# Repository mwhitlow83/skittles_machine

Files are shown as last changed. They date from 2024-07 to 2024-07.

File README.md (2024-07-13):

# skittles_machine
#### Machine that physically separates skittles candy by color

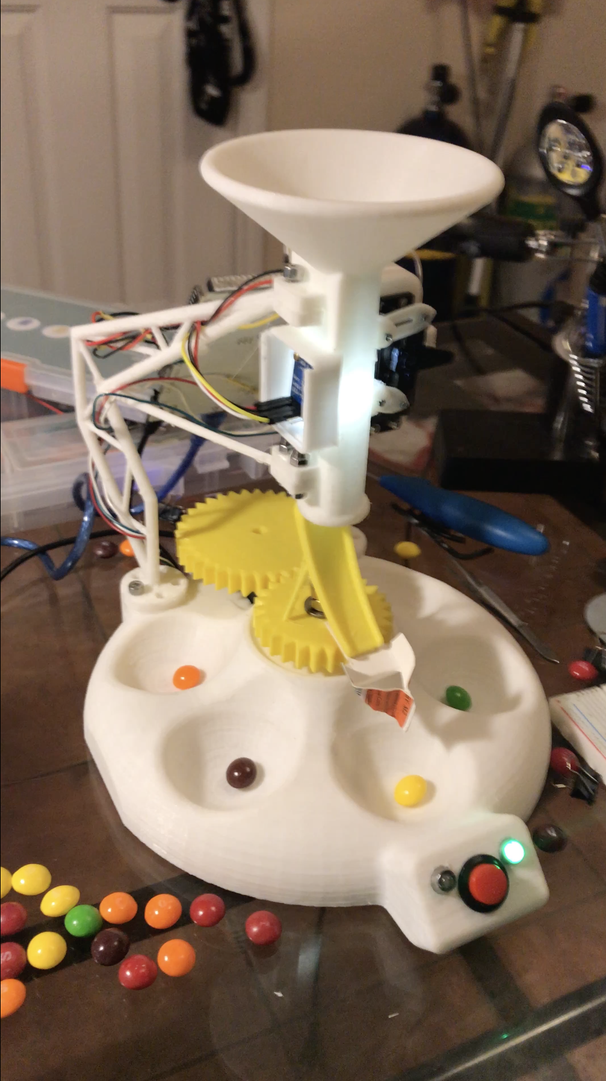
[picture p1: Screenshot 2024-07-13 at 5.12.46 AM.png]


#### Items Required 
Adafruit_TCS34725 color sensor, arduino, 2 servos, leds, resistors and button.

#### Description of operation
One servo is located under the larger gear. in order for the slide to reach 270 degrees of rotation with a servo thats limited to 180 degrees a gear system is needed.

The second servo is located in the processing housing and it operates in the means of allowing one skittle at a time to be analysed by the color sensor. See photo
 below.
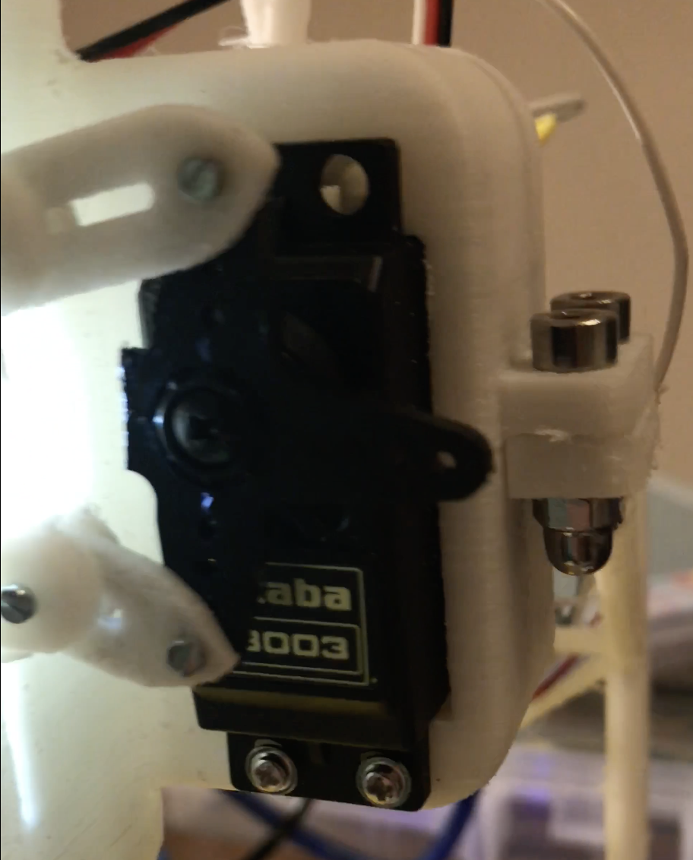
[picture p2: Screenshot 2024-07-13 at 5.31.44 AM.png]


#### Calibration may be needed
The raw ADC value range for each color are used in condiitonal statements to indentify the color. The range was calculated by recording the ADC values of 10 pieces of 1 color and then conditional boundaries are set in the code.

#### Additional Requirments
The initial drop of the skiddles down the sorting slide is greater that what is needed for the skittle not to bounce out of the container. A mechanical structure is needed to slow the velocity of the skittle at the botton of the slide.

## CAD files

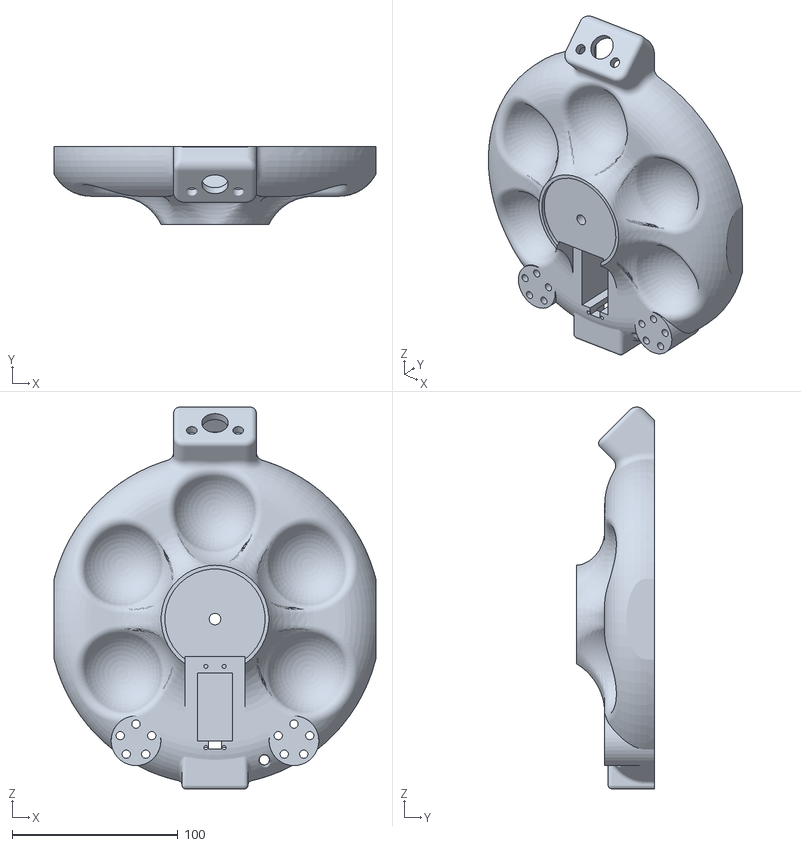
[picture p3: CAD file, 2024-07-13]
STL files/bin base shaved side.STL
194.0 x 47.0 x 230.4

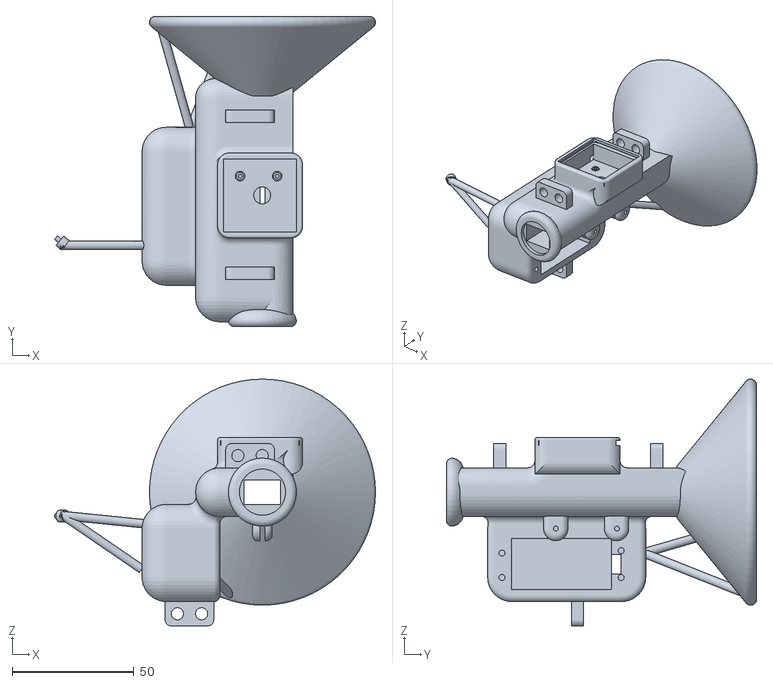
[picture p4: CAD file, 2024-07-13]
STL files/servo housing w color sensor.STL
132.0 x 127.6 x 101.5

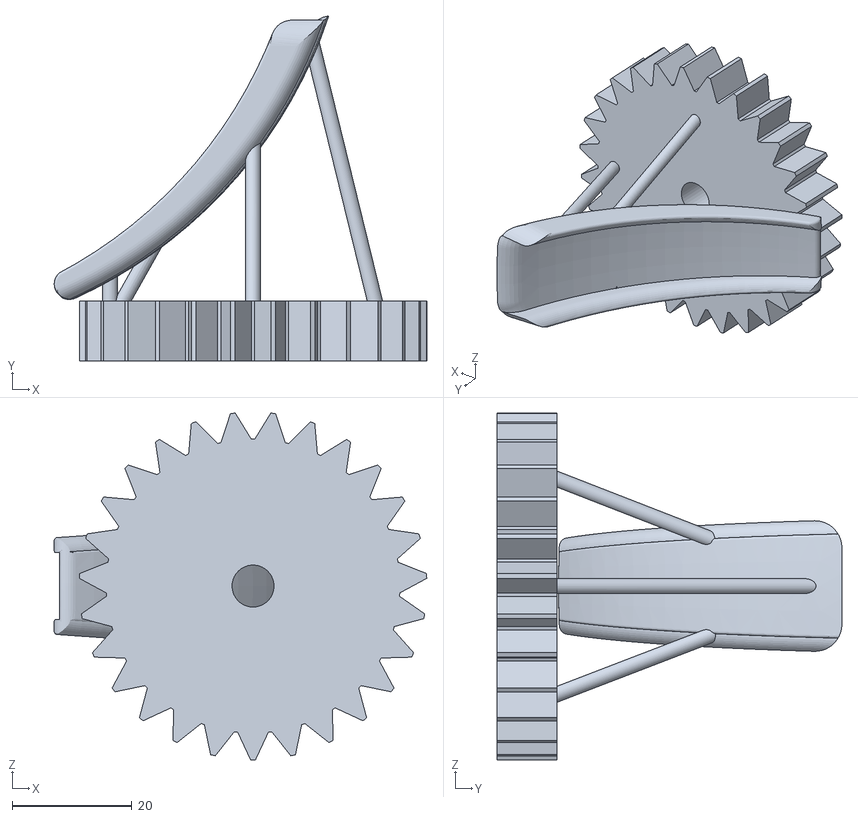
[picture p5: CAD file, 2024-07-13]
STL files/slide gear with slide.STL
62.1 x 57.5 x 57.9

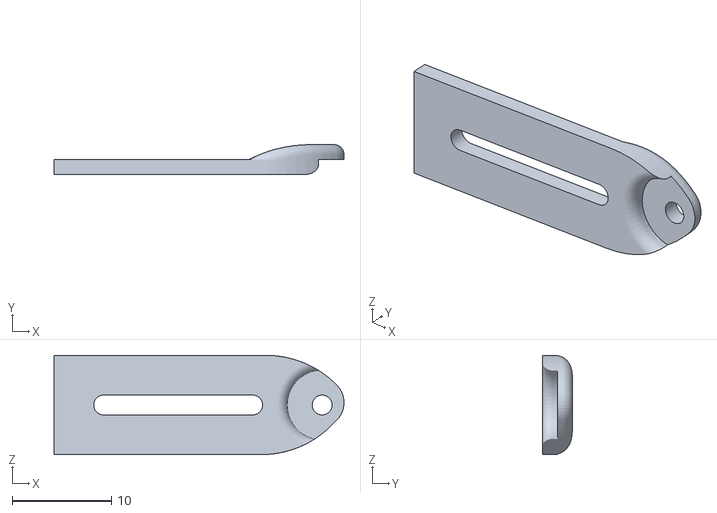
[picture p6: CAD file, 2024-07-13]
STL files/lower linkage.STL
29.2 x 3.00 x 10.0

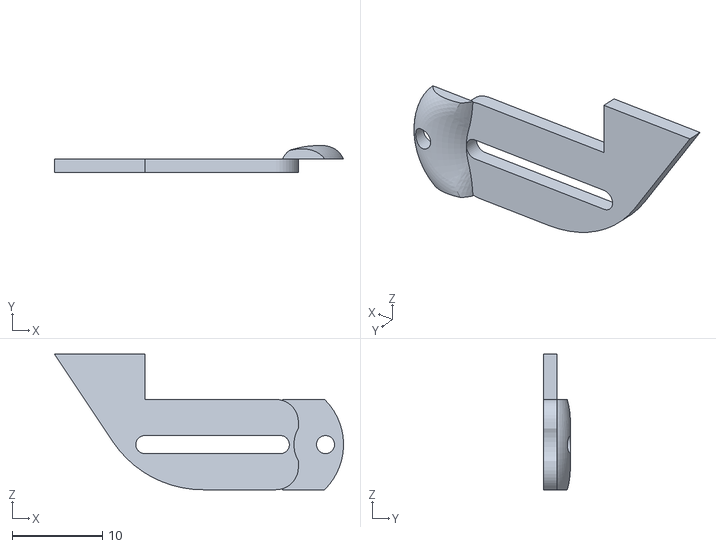
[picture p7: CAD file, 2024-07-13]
STL files/upper linkage.STL
32.0 x 3.00 x 15.0

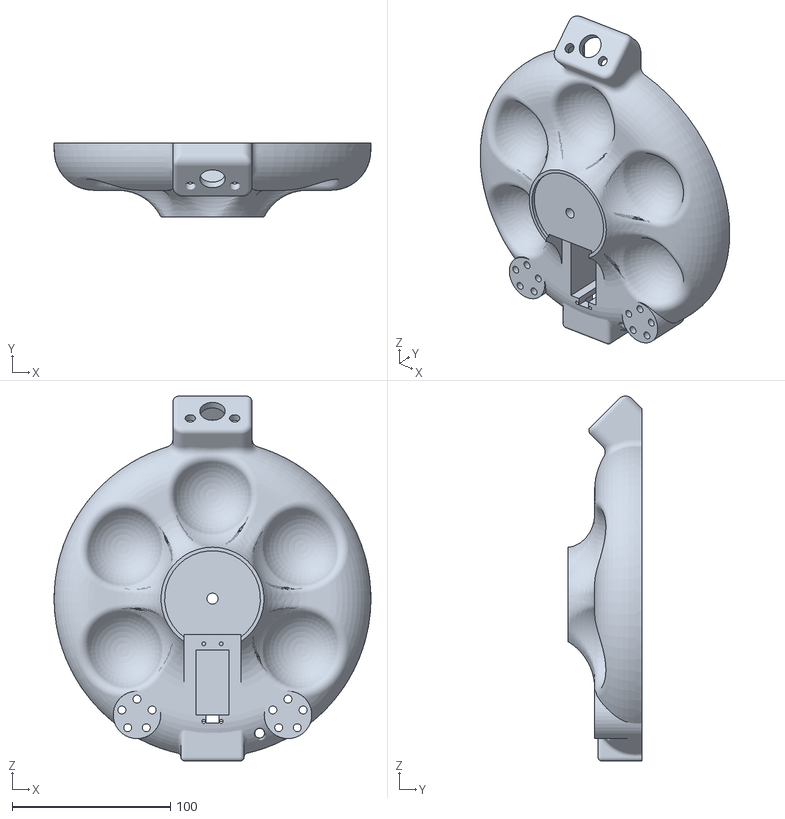
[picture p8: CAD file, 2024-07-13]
STL files/bin base.STL
199.9 x 47.0 x 230.4

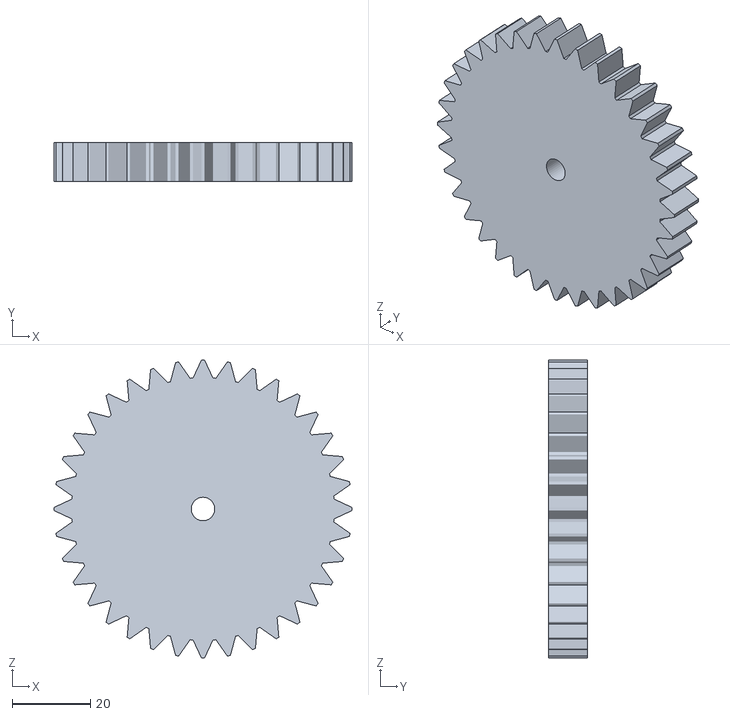
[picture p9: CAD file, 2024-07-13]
STL files/servo drive gear.STL
76.0 x 10.0 x 76.0

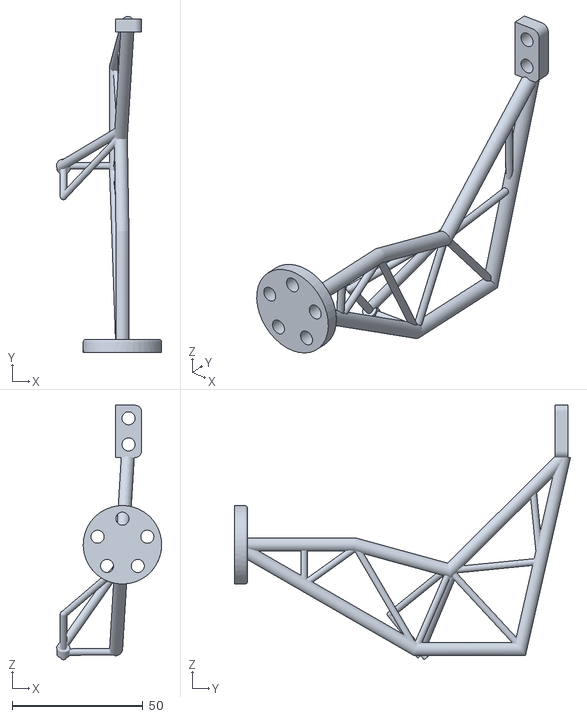
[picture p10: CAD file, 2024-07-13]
STL files/right support.STL
40.3 x 128.5 x 97.4

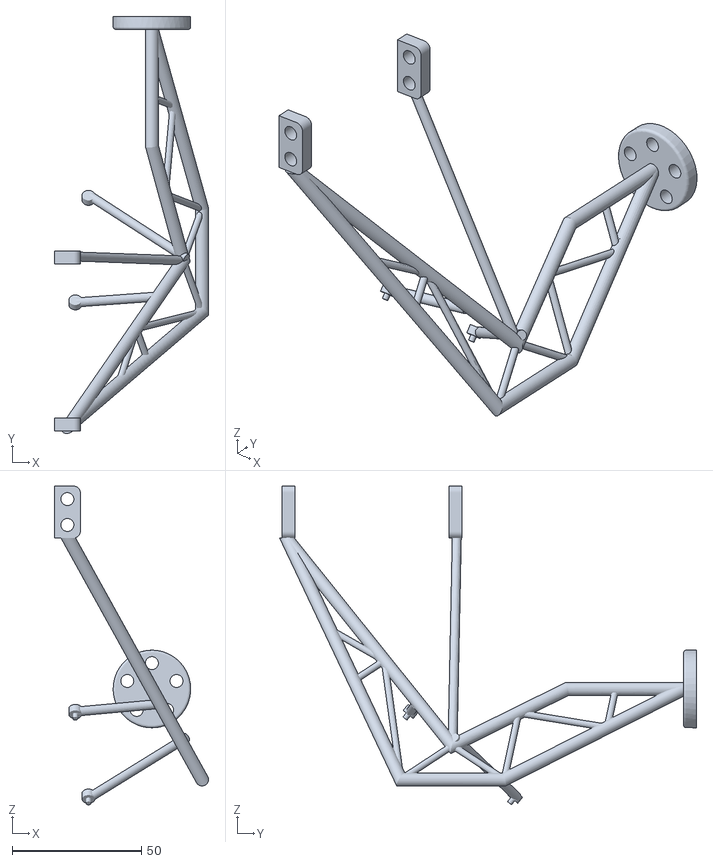
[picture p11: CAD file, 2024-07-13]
STL files/left support.STL
59.5 x 161.2 x 123.2

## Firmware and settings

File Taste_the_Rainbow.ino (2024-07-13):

//Programed by Matthew Whitlow
//Open Design project "Taste the Rainbow"

#include <Wire.h>
#include "Adafruit_TCS34725.h"
#include <Servo.h> 

Servo next;         //servo is attached to mechanism that allows one skittle at a time to pass in front of color sensor
Servo bin;          //servo is attached to a slide that directs skittle to selected coler bin.

//identifies frequency from sensor. sorted blue, red, green and clear
Adafruit_TCS34725 tcs = Adafruit_TCS34725(TCS34725_INTEGRATIONTIME_50MS, TCS34725_GAIN_4X); 

const byte interruptPin = 2;        //button input to start skittle sorting process 
volatile byte state = LOW;

int redled = 12; //red led
int greenled = 8; //green led

void setup() {
  
  pinMode(redled, OUTPUT);
  pinMode(greenled, OUTPUT);
  
    next.attach(9);
    bin.attach(10);
    
       Serial.begin(9600);
       Serial.println("Taste the Rainbow!");

     if (tcs.begin()) {
        digitalWrite(greenled, HIGH);
        Serial.println("Clear Blue Skys");
       }
        
      else {
         digitalWrite(redled, HIGH);
         Serial.println("Cloudy Outside, No Rainbow");
        while (1); // halt!
      }
  
  pinMode(interruptPin, INPUT_PULLUP); //at anytime process can be stopped with button press
  attachInterrupt(digitalPinToInterrupt(interruptPin), getColor, CHANGE);
   
   bin.write(87); //position servos on startup
   next.write(91);      
}

void loop(){
  
  int i=0;
  int color=0;
  int off=1;
   
      while (state == 1){     //starts processing color
    
          digitalWrite(greenled, HIGH);
          digitalWrite(redled, LOW);
  
          uint16_t clear, red, green, blue;

          delay(700);  //allow time for color processing  
  
          tcs.getRawData(&red, &green, &blue, &clear);

                if((red<9728)&&(red>8400)&&(green<10774)&&(green>10100)&&(blue<10281)&&(blue>9400)){  //conditions for red skittle
                    Serial.print("red\n");
                          color=1;
                    }
  
                else if((red<9570)&&(red>8500)&&(green<14440)&&(green>13000)&&(blue<11217)&&(blue>10200)){   //conditions for green skittle
                    Serial.print("green\n");
                          color=2;
                    }

                else if((red<19000)&&(red>13900)&&(green<18800)&&(green>15300)&&(blue<12700)&&(blue>10900)){ //conditions for yellow skittle
                    Serial.print("yellow\n");
                          color=3;
                    }
    
                else if ((red<8200)&&(red>7100)&&(green<10900)&&(green>10000)&&(blue<10300)&&(blue>9200)){ //conditions for purple skittle
                    Serial.print("purple\n");
                          color=4;
                    }
    
                else if((red<15600)&&(red>9126)&&(green<13100)&&(green>10800)&&(blue<11400)&&(blue>9900)){
                     Serial.print("orange\n");                                                   // conditions forced for orange skittle
                          color=5;
                    }

                else if((red<8200)&&(red>8000)&&(green<11100)&&(green>11000)&&(blue<10300)&&(blue>10100)){
                     Serial.print("out of skittles\n");
                          off=0;
 
                              while((off==0)&&(state==1)){  //flashes red led for user to reload
                                        
                                          bin.write(90);
                                        digitalWrite(greenled, LOW);
                                        digitalWrite(redled, HIGH);
                                          delay(500);
                                        digitalWrite(redled, LOW);
                                          delay(500);
                                  }
                         
                    }

   
  Serial.print("C:"); Serial.print(clear);             //print used for determining skittle colors
  Serial.print("\t\tR:"); Serial.print(red);
  Serial.print("\t\tG:"); Serial.print(green);
  Serial.print("\t\tB:"); Serial.print(blue);
  Serial.println();
  Serial.println();
                                   
 state=0;
 
        }   
        
            while(color!=0){             //directs skittle to bin
    
                  if (color==1){               // bin locations
                         bin.write(0);}
    
                  else if (color==2){
                        bin.write(45);}

                  else if (color==3){
                        bin.write(87);}

                  else if (color==4){
                        bin.write(133);}

                  else if (color==5){   //orange bin
                        bin.write(176);}
      
                    delay(1200);  //allow time for servo to reach bin destinatin
        
            state=off; //skips servo cycle if no skittles are in shoot
   
        next.write(115);         //servo postion to drop skittle on to slide
          delay(500);
        next.write(91);          //servo position to load next skittle in front of color sensor
          delay(200);
        
        color=0;                 //reset color for next 
        state=1;                 //process next skittle
   
       }
}     
  void getColor() {     //interupt function changes state at anytime button is pressed
  state = !state;
}

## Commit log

2024-07-13 added stl files for 3D printer
    [bin base shaved side.STL, bin base.STL, left support.STL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]
2024-07-13 added Arduino code
